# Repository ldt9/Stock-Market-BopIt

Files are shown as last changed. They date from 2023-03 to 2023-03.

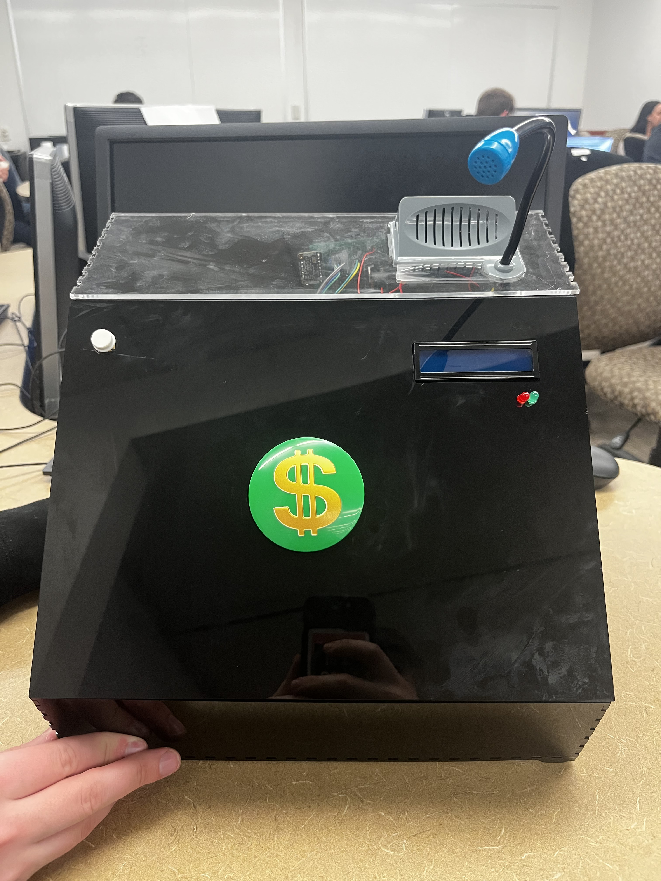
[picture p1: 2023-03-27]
Enclosure Design Files/ProductImages/IMG_0331.jpg

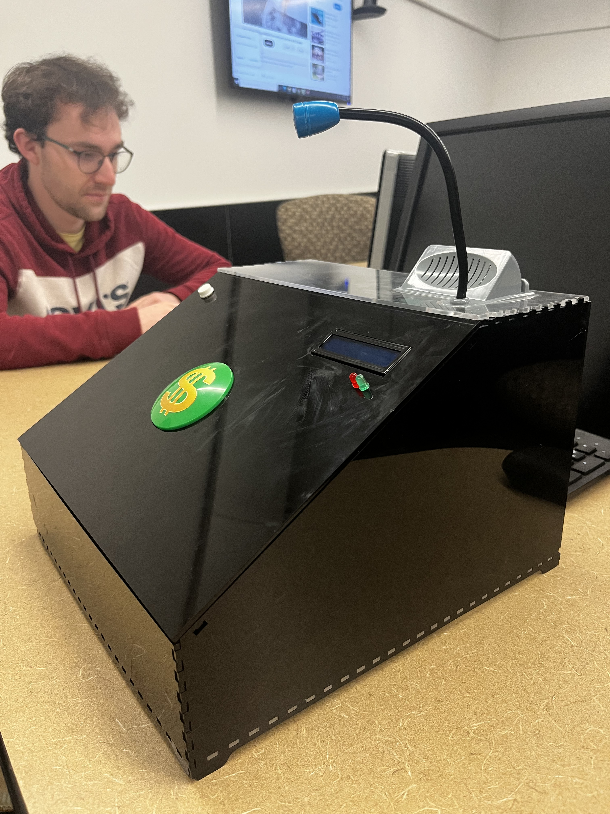
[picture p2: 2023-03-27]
Enclosure Design Files/ProductImages/IMG_0332.jpg

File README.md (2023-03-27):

# Stock Market Bopit

## Project Overview

The Stock Market Bopit is a game that allows players to simulate trading stocks by using physical actions to make decisions. The game has three different actions that players can take: hitting a "Buy" button to buy a stock, yelling into the sound detector to sell a stock, and shaking the device to hold onto a stock.

The game was created by my group for a Junior Design project as part of my ECE Courses at the University of Pittsburgh. It is modeled to look like a toy cash register, but with more functionality.

## Technologies Used

- Arduino Uno
- Sound Detector
- Buttons
- Gyroscope
- LEDs

## How to Play

1. Flip the switch on the rear of the unit to turn the machine on.
2. Press the start button to begin the game.
2. The game will display a required action such as Buy, Sell or Hold.
3. To buy the stock, hit the "Buy" button.
4. To sell the stock, scream "Sell" into the microphone.
5. To hold onto the stock, shake the Bopit. 
6. Each time a player successfully completes an action, they will recieve one point, and the game time per action will decrease to make it faster and more difficult.
6. The game will continue until the player reaches a score of 99 or fails to complete an action in the required amount of time.
7. The player's final score will be based on the total number of successful bopits.

## Files in the Repo

There are a few files in this repository that are noteable. First is the code. It has the file extension `.ino` which is meant to be loaded into an Arduino. The code contains the game loop, sounds, and over functionality of the Bop It. Next is the enclosure design. This has the file extension `.svg` which is meant to be loaded into a laser cutter or another milling machine. We used laser cut arylic for our design as you can see in the photos below. Lastly are the Altium files. These contain gerber files that are meant to be sent to PCB manufacturer for milling. You could use these, along with the included schematics in order to recreate our Bop It.

## Photos








## Conclusion

The Stock Market Bopit was a fun and interactive way to learn about Arduino's and how to interface with them. My group and I had a fun time making this project, and it taught us many valuable lessons about circuit design, programming, and most of all, teamwork!

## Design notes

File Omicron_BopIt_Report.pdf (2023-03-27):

# Design Project 2: Bop-it! Project Final Report

### Design Overview

The Stock Market Bop-It game is an interactive simulation of stock trading where players use physical actions to make decisions. The game involves three main actions: hitting the "Buy" button to purchase a stock, yelling into the sound detector to sell a stock, and shaking the device to hold onto a stock. The Bop-It design is modeled after a cash register, adding to its realism.
Originally, we had thought to use a microphone for the sound input. However, upon further review and research, we determined that a microphone was unnecessary as it would require an amplifier and recording capabilities, which were not needed for detecting sound. Instead, we replaced the microphone with a sound detector, simplifying the design.
Initially, the design for the Bop-It game included an RFID card swipe to start the game. During testing, it was discovered that the RFID scanner required a 3.3V input, while the rest of the circuit used a 5V input. We evaluated alternative RFID scanners, but after reviewing the (few good) available libraries, we decided to replace the RFID card swipe with a button, as it was not critical to the game's functionality and only an added feature.

### Design Verification

The design verification for the Bop-It first included tests of our sensors. These tests revolved around gaining a better understanding of how they worked and how to best interface them with the Arduino. This first set of testing lead us to our first change in our device which was removing the RFID card swipe and replacing it with a button for the start. We made this decision after extensive testing on the RFID card swipe and realized that it was going to be much less reliable and cause more problems than it was worth, leading to replacing it with a simple button.
The next step in our design verification was to interface all the sensors with the Arduino. This process was crucial for further progress as it set up the layout for the PCB and allowed us to finalize the software for a full test of our initial prototype. This step involved us using a breadboard and the datasheets for the sensors to determine where we must interface the sensors.
The last thing we did during design verification was to determine the best way to make the enclosure. At first, we started with the idea of gutting an existing toy cash register and putting our Bop-It inside. This plan got changed as we realized the many problems that come up when using a pre-existing enclosure including hole sizing. Our plan after that included changing our enclosure design to one that we would laser cut holes to better fit all our sensors and our general design.

### Electronic Design Implementation

To implement the PCB design, we began by designing a schematic based on testing of each component used in the circuit. To ensure error-free implementation, the circuit was first fully tested on a breadboard before the PCB schematic was created. To organize the multiple pin outputs on the circuit, we created an excel file for each pin output on the ATMEGA328P IC.
For a stable power supply, we added a voltage regulator to the circuit to provide a constant and controlled voltage to the rest of the circuit. Additionally, a capacitor was included from power to ground and a crystal with two capacitors on opposite sides of the crystal to set up the ATMEGA chip and ensure its proper functioning. To connect components like the gyroscope, sound sensor, LCD screen, start and buy buttons, and speaker, we used jumper components, since these components are not attached to the board but rather to the housing design.
A potentiometer was added in series with the speaker to control the volume level before it was put into the housing. Two LED lights and resistors were also added to the design to signify if the action was completed within the time frame for our game. We included a jumper to reprogram the ATMEGA in case we found a flaw in the code and needed to easily change it.
To lay out the PCB, we placed the jumpers for the gyroscope, sound sensor, LCD screen, buy and start buttons, speaker, pins for reprogramming, and power supply around the perimeter of the board for an organized way of connecting the board to the components. The ATMEGA328P IC was placed in the middle of the board since most components were connected to it, making routing more efficient. The potentiometer was also placed in the middle for easier adjustment of resistance without interfering with wires coming off the board.
The two capacitors were placed to the left of the ATMEGA328P IC, as that was the most efficient route without interfering with the rest of the circuit. The 5V regulator was placed next to the capacitor across the power and ground terminals, which is next to the power jumper. The remaining diodes and resistors were placed below the crystal to fill the board. We used an autoroute program to correctly route the circuit and had no errors in routing but faced some trouble in routing the circuit to the buy button input due to its unique design. To solve this problem, we soldered two jumper wires from the button leads of the cash button PCB through the speaker holes and to the main PCB.
During testing, we found that the buy button would only work as an input if it was turned on, and that whenever the main power supply was turned off, the cash button would make a sound even when it was not pressed. We also discovered that we initially used too high of a resistance for the green and red LEDs, resulting in them being too dim, so we replaced the 10k resistor with a 1k resistor to achieve the desired brightness level.
One error we made was not including a power switch on the board, but we easily rectified this by connecting the positive lead from the battery wire to a switch, which had a jumper wire to the positive end of the power supply jumper, while the negative end of the battery connected to the ground terminal jumper.

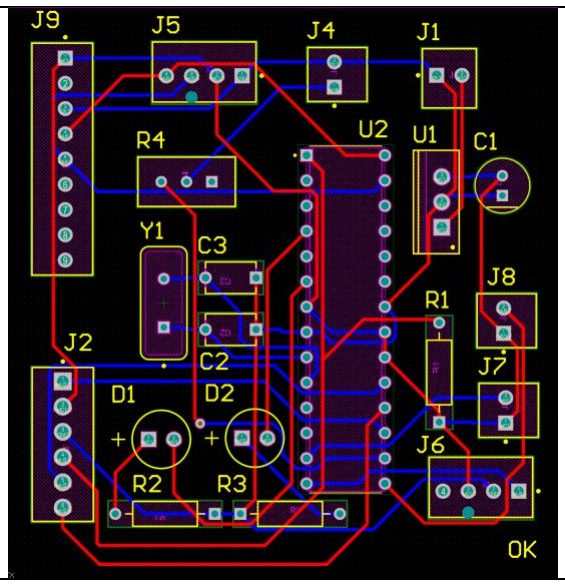
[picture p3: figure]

PCB Layout of circuit.

### Software Implementation

The software developed for this project is based on Arduino. The main functionalities of the software are to read data from sensors, display prompts on the LCD screen, play sound, and handle user input. The sensors used in the project are a gyroscope, sound detector, and buttons. The LCD screen is used to display instructions to the user. The code is structured in a way that a game loop is run continuously until the user fails to complete a task in time or reaches a score of 99. During each iteration of the game loop, the state of each sensor is read and instructions are displayed on the LCD screen.
The subroutines developed and used in the final software implementation are as follows:
1. setup(): This subroutine is used to initialize the variables and sensors used in the project.
2. loop(): This subroutine is the main game loop, which runs continuously until the user fails to complete an action in time or reaches a score of 99. The loop first reads the state of the sensors and decides which random action to prompt the user to perform. This decision is fed to the actionDetector() sub routine where it displays the unique instruction on the LCD screen, makes a distinct noise and waits for user input. If the user performs the action within the given time, the score is incremented, and the loop continues. If the user fails to perform the action within the given time, the loop is terminated, and the final score is displayed on the LCD screen.
3. actionDetector(int action, int actionPin, String actionText, bool digital): This subroutine is called when the user is prompted to perform one of the three actions. It plays the melody associated with the action, displays the required action to the LCD screen and lights up the green LED upon completion, or the red LED upon failure. It can handle both digital and analog sensors.
4. playMelody(int melody[], int length): This subroutine is used to play the melody associated with each action. It takes an array of notes and their duration as input and plays them using the tone() function.
The code is structured in a modular way, with each subroutine responsible for a specific task. This makes the code easy to understand, modify, and maintain. The use of descriptive function names also helps in understanding the purpose of each subroutine. The code follows good software engineering practices, such as modularization, documentation, and readability. The code is also well commented, making it easy to understand for other developers.
The design process involved breaking down the problem into smaller tasks and implementing them one by one. The first step was to initialize the sensors and test their functionality. Then we designed the game loop and implemented the code to read sensor data and display instructions on the LCD screen. We then added sound and LED feedback to the game. The main challenge in the design process was to handle user input within a limited time frame. We overcame this challenge by using the millis() function to measure the time elapsed and terminate the loop if the user fails to perform the action within the given time. We also had to optimize the code to make it run efficiently within the limited resources of the Arduino board.

### Enclosure Design

At first our enclosure design was going to be of a toy cash register with 3D printed parts to make the hole fit our needs. This idea soon changed as we worked through the process of disassembly and eventually changed to using a laser cutter to create our enclosure. We decided on this design method due the simplicity of our box allowing for quick and easy laser cutting.
The structure of our enclosure is meant to mimic the look and size of a cash register to fit the theme of our Bop-It. There are a couple of cutouts on our Bop-It to allow interactions with our inputs. There was a total of 6 cutouts all done with the laser cutter. The cutouts hold the LED screen, LED lights, speaker, sound detector, buttons, and a power switch. Our design also features a piece of a toy cash register that holds both the speaker and sound detector while adding an aesthetic microphone to make the feel and visual appeal of our Bop-It more like a cash register.
For our manufacturing process we used laser cutting. Because of the size of our Bop-It, laser cutting wasn’t as simple as we had thought. One of our pieces was too big to be cut out in one piece. The solution to this problem was to modify the cutout to make it 2 sperate pieces. One unplanned feature we got from laser cutting that we didn’t really plan was for a clear top and bottom, however, this was a happy accident as these pieces allow you to see into the enclosure and look at the circuit without opening the box.

### Assembly and System Integration

For the PCB assembly, pinheads were used at each of the jumpers and soldered accordingly, with the exception for the gyroscope which had pinheads soldered to it. These pinheads fit perfectly into the PCB and then soldered. Once everything was soldered female to female, and female to male wires to connect each circuit component to the PCB and give each component the length needed to fit within the design.
Our design had a couple steps in assembly. The first was to get the pieces without cutouts together to form a base for the rest of the enclosure to be built on. This proved to be more challenging than we thought as the pieces were cut to fit very tightly together leading to problems assembling and lead to some pieces cracking or breaking during assembly. The next step in this process was to attach the inputs and outputs to their intended cutouts with hot glue. This also had some problems due to tight cutout and we had to use a Dremel to remove the extra material. Another problem encountered was that one of our cutouts was oriented the wrong way and lead to the top not fitting on as intended.
We tested our design thoroughly at each step of the way first starting with the PCB implementations. Then as we attached more parts to the enclosure, we tested it incrementally before fully enclosing the design. One modification we made to our design was an added set of pins to our board to allow easy access to the Arduino for code updates and changes if we ever needed it.

### Design Testing

Electronic Design Testing
There wasn’t much debugging to do throughout the whole process other than our big green button in the center of the product. Since this was already made into a separate product, and there was power used to make a “Cha-Ching” noise, when we tried to implement it into our design it didn’t work as an input to the Arduino at first. We hypothesized that there was probably a different part of the device it was grounding to and not giving the Arduino a high signal, it was looking for. It took a few times of resoldering it, but after trying a few permutations about the button leads, we landed on a set that worked both as an input and to produce the sound we were looking for.
One small thing that had to be debugged was the LEDs. At first, they did not light up but upon further testing it turned out they were put in the wrong way. On the silkscreen there is a “+” sign on the left side of the LED. This turned out to be the negative end of the LED. We have learned now to check to see if the part design in Altium is correct before hooking up a circuit. Since the voltage here was so low it did not damage anything but if it were a higher voltage circuit it could have caused problems and broken components. Also, the LEDs were much dimmer than our group initially intended. To fix this problem our group decided to lower the resistance of the resistors in series with the LEDs from 10k to 5k.

Software Testing
To ensure the software components of our design were functioning correctly, we began by unit testing each individual component. Through this process, we were pleased to discover that our Arduino, programmer, sound detector, buttons, LEDs, gyroscope, LCD screen, and speaker were all functioning flawlessly. The only roadblock we encountered was with our RFID scanner, which required a 3.3V voltage rather than the 5V voltage we were using for the rest of the circuit. While we could have employed a voltage regulator to address this issue, we made the decision to keep the design simple and not introduce multiple voltages. For a comprehensive look at our unit tests and code, you can find them readily available on our GitHub (https://github.com/ldt9/Stock-Market-BopIt) page along with the attached folder.
Once we had confirmed that each individual component was in working order, we then began the process of integrating these individual tests into a cohesive game loop. We began by adding some initial text to the LCD screen and verifying that we could initialize it into both the setup() and loop() routines. We then moved on to integrating the start button and ensuring that an input to the digital pin would correctly prompt different text. With these initial tests in place, we created an action handler that would generate a random action to be displayed on the LCD screen and then wait for user feedback. Initially, we used three buttons to represent the various inputs and to establish functioning digital pins. As we progressed, we slowly swapped out two of these buttons for their respective game input counterparts, testing each new addition as we went along to identify and address any potential issues. Fortunately, each new addition worked exactly as we had intended.
Once we had verified that all inputs were functioning correctly on the breadboard, we then began to add sound to the game. To achieve this, we developed a subroutine to handle generating appropriate noises for each action. After establishing the subroutine, we then integrated it with the action handler and thoroughly tested the game loop. The final step was to add LEDs to indicate when players had made correct or incorrect actions, giving us a fully functional game loop with integrated inputs and outputs. With these tests complete, we were confident in our design and ready to begin the process of soldering the components to the board and assembling it inside the enclosure.

Enclosure Testing
The testing of the enclosure started with our first model for our enclosure and lead to failure after we realized that it would be difficult to get the premade enclosure to fit our needs and it would be simpler to create a laser cut enclosure. After this first design, we moved to a laser cut model of the enclosure which had its own set of problems during testing. The first problems arose as we were assembling it, it included parts cracking or breaking and cutouts being slightly off in size. The last problem we found with the box is the cutout for the top was oriented the wrong way leading to us having to improvise the attachment of the top piece.
Although our design was able to work in the end there were some problems, we would have addressed it if we had more time to cut out a second enclosure. Another part of the testing was making sure our enclosure would hold together as it was played as it had to be shaken for one of the commands. We tested this and the other inputs on the box though a series of test run to ensure the enclosure could handle being played. The only flaw that was found during this testing was that if the buy button is pressed down too hard, it sometimes would shift and not fit into the cutout as well. This didn’t lead to any problems with the inputs, just an aesthetic problem. Below you will find some photos of the fully assembled product.

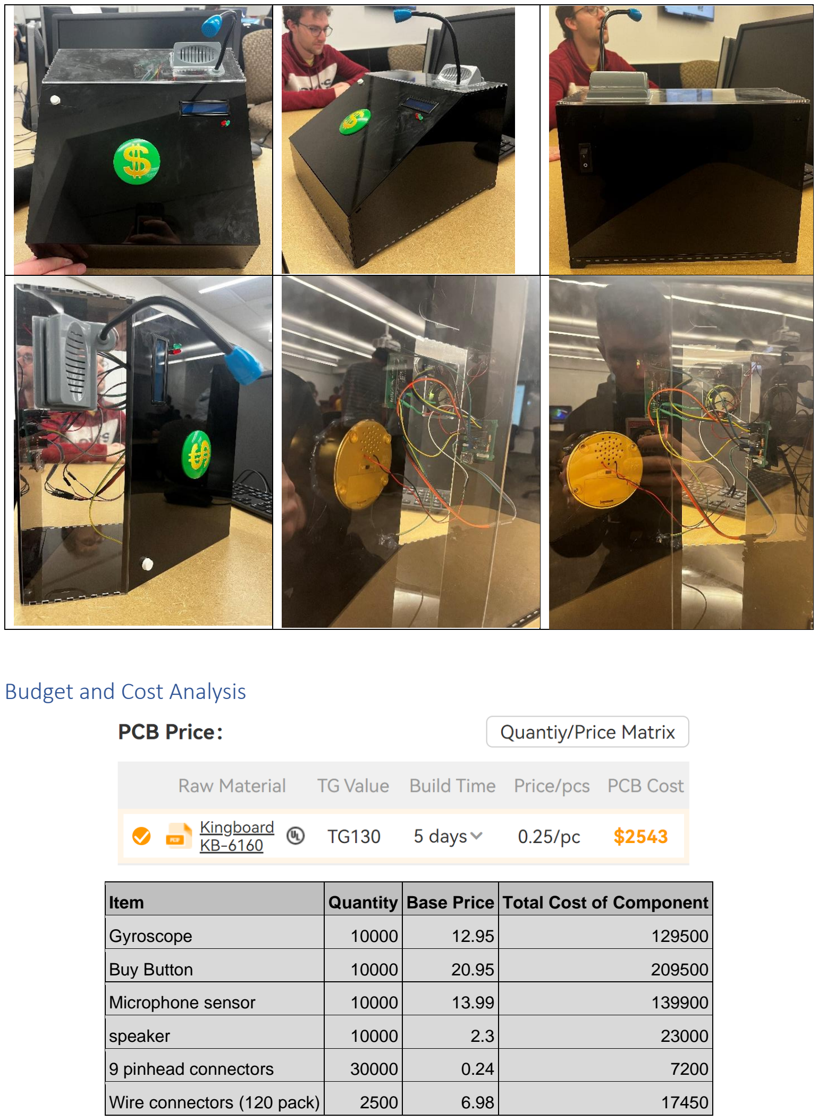
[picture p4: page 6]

### Budget and Cost Analysis

Item | Quantity | Base Price | Total Cost of Component
Gyroscope | 10000 | 12.95 | 129500
Buy Button | 10000 | 20.95 | 209500
Microphone sensor | 10000 | 13.99 | 139900
speaker | 10000 | 2.3 | 23000
9 pinhead connectors | 30000 | 0.24 | 7200
Wire connectors (120 pack) | 2500 | 6.98 | 17450

PCB | 1 | 2543 | 2543
ATMEGA328P IC (10 pack) | 1000 | 50 | 50000
Potentiometer | 10000 | 0.6 | 6000
PVC | 30000 | 35 | 1050000
Crystal | 10000 | 0.18 | 1800
10uf Cap | 10000 | 0.25 | 2500
LED | 20000 | 0.18 | 3600
Resistor | 30000 | 0.45 | 13500

Total cost
of Design

$1,656,493

### Team

Lucas worked on the software aspects of the design. He headed writing the code and uploading it to the Arduino, as well as early stage breadboarding and testing. Then, as we met regularly as a group, we all helped during debugging of the circuit and ultimately creating what would be the final design for the PCB schematic. He also handled creating our initial workflow and GitHub page.
Andrew worked on the enclosure design and helped on the electrical side including back checking the PCB schematic, testing sensors, and organization of inputs. He also handled the enclosure final cutout and assembly as well as assisting in the hookup of the PCB and sensors to the enclosure frame.
Owen designed the PCB and helped to test components. He also worked on the electrical aspect of the buy button. Owen helped with the final assembly of the design, ensuring each component went in the correct spot.
Throughout the design process, we would meet weekly in the Fishbowl for two to three hours at a time to finish our design. We used SMS messaging and email to update each other on the design process as well as meeting times. We felt it was best to meet in person to do the physical testing and assembly, but for report generating and presentations making, it was fine to do it remotely. We believe our team worked great together, and that it was our primary reason for being able to complete our project in such a timely manner.

### Timeline

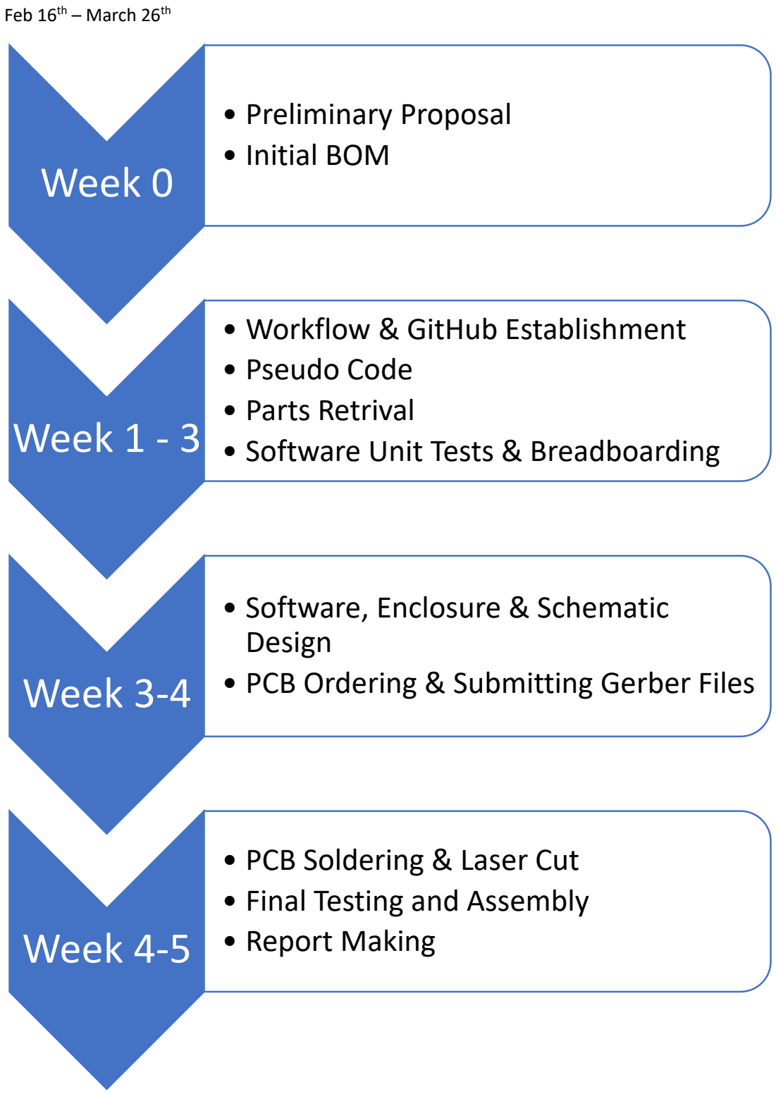
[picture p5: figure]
Feb 16th – March 26th; Week 0; • Preliminary Proposal • Initial BOM; Week 1 - 3; • Workflow & GitHub Establishment • Pseudo Code • Parts Retrival • Software Unit Tests & Breadboarding; Week 3-4; • Software, Enclosure & Schematic Design; Week 4-5; • PCB Soldering & Laser Cut • Final Testing and Assembly • Report Making

## - PCB Ordering & Submitting Gerber Files

### Summary, Conclusions and Future Work

In conclusion, the Stock Market Bop-It game was a great way to learn team building skills and practice real on-the-job skills. Through a series of design iterations and testing, our team was able to refine the initial concept and create a fully functioning prototype. The decision to replace the RFID card swipe with a button, switch to a sound detector for sound input, among many other pivots, were crucial design changes that simplified the circuit and improved its reliability. The team's attention to detail in sensor interfacing and enclosure design resulted in a polished final product that met the project's goals. There are several areas in which the software logic could be improved. For instance, when the ON switch is toggled, the game starts without requiring the start button to be pressed. During initial breadboarding and PCB testing, this didn't pose a problem, but once we assembled everything, the start button was skipped on the first game. After completing or losing the first game, the start button worked correctly, waiting for user input before prompting for actions. We're uncertain why the start button fails during the first round since the code worked correctly initially. Additionally, we overlooked implementing cases where pressing the wrong action would result in losing the game. If we had more time, we would have passed all the sensors to the action handler and added a clause to lose the game if the state of non-prompted actions changed. We could have also attempted to order another RFID scanner running on 5V, but the available libraries were not user-friendly enough for our liking. Lastly, in a later model, we would add a "press to talk" button before speaking into the sound detector to prevent exploiting the loophole of repeatedly pressing the buy button to win the game by triggering the "Cha-Ching" sound.
Reflecting on our Bop-It project, we've identified a few areas in which we could improve the enclosure design. Firstly, we would have opted for a smaller size, as the benefits of a larger size were outweighed by issues with production, assembly, and gameplay. To make the enclosure more visually appealing, we would have liked to add stickers or other decorative elements to showcase the theme and attract more attention to the device. Additionally, we would have improved the box's fit, as the tightness of the enclosure caused some damage during use, and we would have addressed issues with hole sizing to ensure a better fit for components such as the LED screen.
Another significant change we would have made is creating a mount for the battery, as currently, it is only attached to the side of the Bop-It enclosure with hot glue. This would have made replacing the battery difficult, so we would have added a battery mount to the PCB or somewhere in the housing to allow for easy battery replacement if needed. Overall, these improvements would have helped enhance the Bop-It's functionality, ease of use, and aesthetic appeal.

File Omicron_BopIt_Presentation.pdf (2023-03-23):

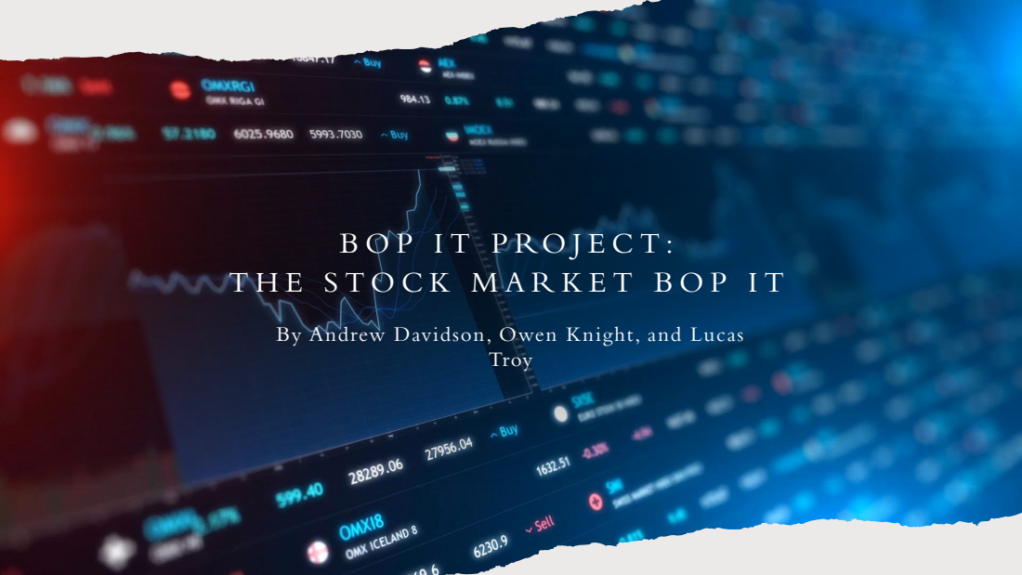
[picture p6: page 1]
Troy

By Andrew Davidson, Owen Knight, and Lucas

# S O F T W A R E I M P L E M E N TAT I O N

- In Arduino’s programming language we instantiate an LSM6DSOX gyroscope, an LCD screen, a sound detector, some buttons, and several pins on the ATMEGA328P to create a game like the Bop It toy with a stock market theme.
- The game has several sensors (buyItPin, sellItPin, and holdItPin) that the user must interact with based on prompts given by the game, such as pressing a button when prompted to “buy,” yelling into the sound detector when prompted to “sell,” and shaking the enclosure when prompted to “hold.”
- There are green and red pins are used to light up the corresponding LEDs, when the user makes a correct or incorrect decision respectively, and the buzzer pin is used to create sound effects through an 8 Ohm speaker.
- The code initializes various variables and arrays, such as the time the user must complete each action within, the current score, and a set of musical notes that can be played through the buzzer.
- The program includes a game loop that waits for user input based on the prompt given by the game. If the user completes the action before the time limit expires, the score is incremented, and the next action is prompted. If the user fails to complete the action or time runs out, the game is over, and the final score is displayed on the LCD screen.
- We have tested the power (input), buttons (input), sensors (input), ATMEGA328P (control) and speaker (output) on a breadboard thoroughly to know the circuit design should work once established on the PCB.
- For simplicity, no code is show, but a repo of this code can be viewed here. (https://github.com/ldt9/Stock-Market-BopIt)

# E N C L O S U R E D E S I G N

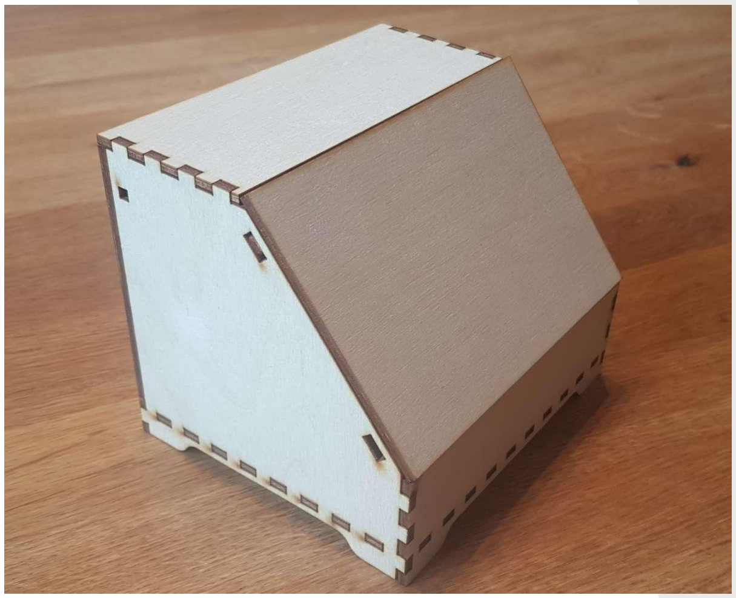
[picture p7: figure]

### - The design is based off the shape of a cash register to fit the theme of our bot-it

game.

- The inputs and outputs such as buttons,

### switches, LED displays, and microphones will have cutouts to allow the user to

interact with them.

### - This design process was picked due to the simplicity of our encloser allowing for it

to be easily done on the laser cutter.

### - The board will be mounted on the floor of the enclosure and the sensors and

outputs will be mounted on their cutouts.

# P C B D E S I G N

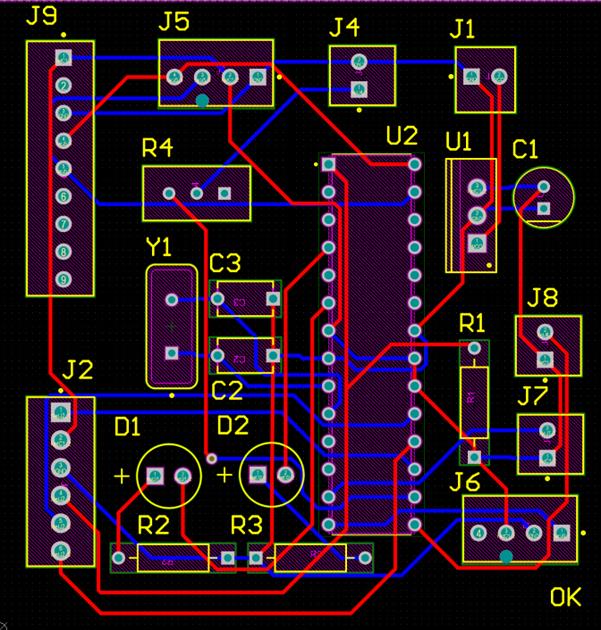
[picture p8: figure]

### •For organization in the enclosure jumper pins are on the outside of the board. Wires connected to these jumpers will be used to put the circuit components in the spot designed in the enclosure •J2 is for uploading new code to the ATMEGA328P IC if need be

•Gyroscope (J9) will be mounted to board.

### •Circuit will be powered by 9V battery (J1) and a 5V regulator (U1) is used to keep the power constant and controlled

## F I N A L D E S I G N O F T H E S T O C K M A R K E T

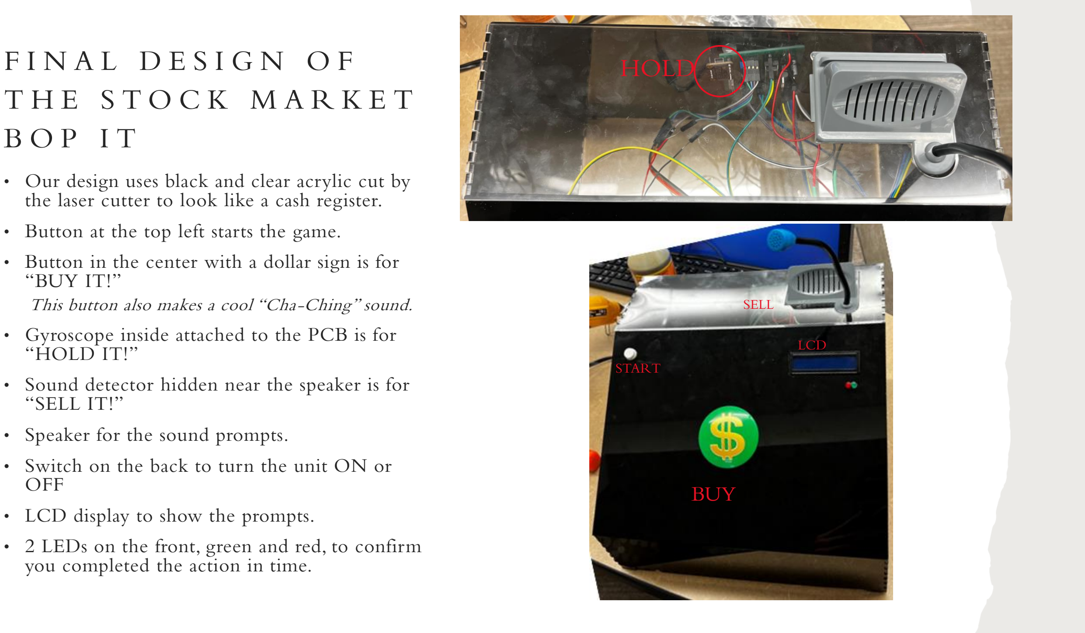
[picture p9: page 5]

## B O P I T

- Our design uses black and clear acrylic cut by the laser cutter to look like a cash register.
- Button at the top left starts the game.
- Button in the center with a dollar sign is for “BUY IT!”
This button also makes a cool “Cha-Ching” sound.
- Gyroscope inside attached to the PCB is for “HOLD IT!”
- Sound detector hidden near the speaker is for “SELL IT!”
- Speaker for the sound prompts.
- Switch on the back to turn the unit ON or OFF
- LCD display to show the prompts.
- 2 LEDs on the front, green and red, to confirm you completed the action in time.

## HOLD

START

BUY

LCD

SELL

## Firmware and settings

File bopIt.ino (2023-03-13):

//TODO:
// Add Speaker functionality

// https://mhsp18object.wordpress.com/2018/05/06/project-2-diy-arduino-sensor-bop-it/
#include <string.h>

//Create an Instance of the Gryroscope
#include <Arduino_LSM6DSOX.h>

//Initialize the LCD Screen
#include <LCD_I2C.h> // LCD Library
LCD_I2C lcd(0x27, 16, 2); // Default address of most PCF8574 modules, change according

//sensor pins
int buyItPin = 7;
int sellItPin = 8;
int holdItPin = 6; //Use gyroscope pitch and yaw
int bypass = 9; //To bypass the RFID Scanner during testing
int greenPin =  2;
int redPin = 4;
int buzzer = 10;

//action to perform during each step
long action = 0;

//reference variables for sensor states
int state1 = 0;
int state2 = 0;

//time user has to complete action in milliseconds and related variables for time keeping
unsigned long gameRate = 10000;
unsigned long timeOfPrompt;
unsigned long timeElapsed;

//variable to control game loop
int keepPlaying = 0;
int actionCompleted = 0;
int score = 0;
int finalScore = 0;
int bypassTrue = 0;

//define tones
#define NOTE_B0 31
#define NOTE_C1 33
#define NOTE_CS1 35
#define NOTE_D1 37
#define NOTE_DS1 39
#define NOTE_E1 41
#define NOTE_F1 44
#define NOTE_FS1 46
#define NOTE_G1 49
#define NOTE_GS1 52
#define NOTE_A1 55
#define NOTE_AS1 58
#define NOTE_B1 62
#define NOTE_C2 65
#define NOTE_CS2 69
#define NOTE_D2 73
#define NOTE_DS2 78
#define NOTE_E2 82
#define NOTE_F2 87
#define NOTE_FS2 93
#define NOTE_G2 98
#define NOTE_GS2 104
#define NOTE_A2 110
#define NOTE_AS2 117
#define NOTE_B2 123
#define NOTE_C3 131
#define NOTE_CS3 139
#define NOTE_D3 147
#define NOTE_DS3 156
#define NOTE_E3 165
#define NOTE_F3 175
#define NOTE_FS3 185
#define NOTE_G3 196
#define NOTE_GS3 208
#define NOTE_A3 220
#define NOTE_AS3 233
#define NOTE_B3 247
#define NOTE_C4 262
#define NOTE_CS4 277
#define NOTE_D4 294
#define NOTE_DS4 311
#define NOTE_E4 330
#define NOTE_F4 349
#define NOTE_FS4 370
#define NOTE_G4 392
#define NOTE_GS4 415
#define NOTE_A4 440
#define NOTE_AS4 466
#define NOTE_B4 494
#define NOTE_C5 523
#define NOTE_CS5 554
#define NOTE_D5 587
#define NOTE_DS5 622
#define NOTE_E5 659
#define NOTE_F5 698
#define NOTE_FS5 740
#define NOTE_G5 784
#define NOTE_GS5 831
#define NOTE_A5 880
#define NOTE_AS5 932
#define NOTE_B5 988
#define NOTE_C6 1047
#define NOTE_CS6 1109
#define NOTE_D6 1175
#define NOTE_DS6 1245
#define NOTE_E6 1319
#define NOTE_F6 1397
#define NOTE_FS6 1480
#define NOTE_G6 1568
#define NOTE_GS6 1661
#define NOTE_A6 1760
#define NOTE_AS6 1865
#define NOTE_B6 1976
#define NOTE_C7 2093
#define NOTE_CS7 2217
#define NOTE_D7 2349
#define NOTE_DS7 2489
#define NOTE_E7 2637
#define NOTE_F7 2794
#define NOTE_FS7 2960
#define NOTE_G7 3136
#define NOTE_GS7 3322
#define NOTE_A7 3520
#define NOTE_AS7 3729
#define NOTE_B7 3951
#define NOTE_C8 4186
#define NOTE_CS8 4435
#define NOTE_D8 4699
#define NOTE_DS8 4978
#define REST 0


// change this to make the song slower or faster
int tempo = 360;

int buyMelody[] = {
  //Cantina Band
  NOTE_B4,-4, NOTE_E5,-4, NOTE_B4,-4, NOTE_E5,-4,
};

int sellMelody[] = {

  // Super Mario Brothers 
  NOTE_G5,8, NOTE_FS5,8, NOTE_F5,8, NOTE_DS5,4,
};

int holdMelody[] = {

  //Keyboard Cat
  NOTE_C4,4, NOTE_E4,4, NOTE_G4,4, NOTE_E4,4,  
};

// sizeof gives the number of bytes, each int value is composed of two bytes (16 bits)
// there are two values per note (pitch and duration), so for each note there are four bytes
int buyNotes = sizeof(buyMelody) / sizeof(buyMelody[0]) / 2;
int sellNotes = sizeof(sellMelody) / sizeof(sellMelody[0]) / 2;
int holdNotes = sizeof(holdMelody) / sizeof(holdMelody[0]) / 2;

// this calculates the duration of a whole note in ms
int wholenote = (60000 * 4) / tempo;

int divider = 0, noteDuration = 0;

void setup() {
	//initialize software serial monitor and give a delay for lcd to load
	lcd.begin();
  lcd.backlight();
	delay(500);

  //Initialize the gyroscope
  IMU.begin();

	//setting pin modes
	// pinMode(rfidScannerPin, INPUT);
	pinMode(buyItPin, INPUT);       //Button controls this pin
	pinMode(sellItPin, INPUT);      //Sound detector controls this pin
  pinMode(bypass, INPUT);         //Button to start game
  pinMode(greenPin, OUTPUT);
  pinMode(redPin, OUTPUT);
  pinMode(buzzer, OUTPUT);

	char scoreString[10];
}

void actionDetector(int action, int actionPin, String actionText, bool digital) {
	//if action selected is one, then tell user to "Buy It"
	// lcd.clear();
  // lcd.print(actionText);

  float x, y, z;
  //reset LED States
  digitalWrite(greenPin, LOW); // Green LED
  digitalWrite(redPin, LOW); // Green LED


	//Read button value to track if user has changed it once prompted
	if (digital) {
		state1 = digitalRead(actionPin);
	}
	else {
		// state1 = analogRead(sensor); //Adjust this for the gyroscope
    IMU.readAcceleration(x, y, z);
    // lcd.clear();
    state1 = int(x) + int(y) + int(z);
    // lcd.print(roll);
    // lcd.clear();
  }

	//write "Buy It" to lcd to prompt user
  lcd.clear();
	lcd.print(actionText);

	//record the time you prompted the user
	timeOfPrompt = millis();
	timeElapsed = millis() - timeOfPrompt;

	//while loop checking if user completed action in allowed time
	while (timeElapsed < gameRate && actionCompleted == 0){
		//read switch for comparing to check if action was completed
		if (digital) {
			state2 = digitalRead(actionPin);
		}
		else {
			// state2 = analogRead(sensor);
      IMU.readAcceleration(x, y, z);
      // lcd.clear();
      state2 = int(x) + int(y) + int(z);
      // lcd.print(yaw);
      // lcd.clear();
		}
		//if the switch state changed, then the user completed action
		if (state2 != state1){
			actionCompleted = 1;
			score = score +1;
			gameRate = gameRate - (gameRate * .05);
      delay(500);
		}

		//recalculate timeElapsed
		timeElapsed = millis() - timeOfPrompt;
	}

	//once while loop stops (either due to time running out or completing action)
	//check to see if action was comleted and adjust settings accordingly
	if (actionCompleted == 1 && score == 99){
    lcd.clear();
    lcd.print("Game Won!");
    delay(750);
    finalScore = score;
    gameRate = 10000;
    score = 0; //reset score to 0 for new game
		char scoreString[10];
		sprintf(scoreString,"%4d",finalScore);
		keepPlaying = 0;
    lcd.clear();
		lcd.print("GAME OVER!");
    lcd.clear();
		lcd.write("Score");
    lcd.clear();
		lcd.print(scoreString);

		delay(2000);
  }
  else if (actionCompleted == 1){
    lcd.clear();
		lcd.print("action completed");
    digitalWrite(greenPin, HIGH); // Green LED
		// tone(speakerPin, 10000, 250); // Adust to a better win sound
		delay(250);
		// noTone(speakerPin);
	}
	else if (actionCompleted == 0){
    lcd.clear();
		lcd.print("action failed");
    digitalWrite(redPin, HIGH); // Red LED
		delay(750);
    // tone(speakerPin, 10000, 250); // Adust to a better Lose sound
    delay(250);
    // noTone(speakerPin);
		finalScore = score;
    gameRate = 10000;
    score = 0; //reset score to 0 for new game
		char scoreString[10];
		sprintf(scoreString,"%4d",finalScore);
		keepPlaying = 0;

    lcd.clear();
		lcd.print("GAME OVER!");
    lcd.clear();
		lcd.print("Final Score: ");
    // lcd.clear();
    lcd.setCursor(0, 1);
    lcd.print(scoreString);

		delay(2000);
    digitalWrite(redPin, LOW);                        
	}
}

void loop() {
	// display game start code on lcd
  lcd.clear();
  lcd.print("   Press  the"); 
  lcd.setCursor(2, 1);
  lcd.print("Start Button!");
  delay(500);

	//If button is pressed, go into game.
  bypassTrue = digitalRead(bypass);
	if (bypassTrue){

	//variable to control the while loop running the game until user has failed
	keepPlaying = 1;

		//while loop to keep running game until user has failed and "keepPlaying" is set to zero
		while (keepPlaying != 0) {
			//pick an action to assign the user via a random number generator – upper bound is exclusive
			action = random(1,4);
			actionCompleted = 0;
      lcd.clear();
			lcd.print(action);
      lcd.clear();

			//if else statements to prompt user and check action
		    switch(action) {
				case 1:
            // iterate over the notes of the melody.
            // Remember, the array is twice the number of notes (notes + durations)
            for (int thisNote = 0; thisNote < buyNotes * 2; thisNote = thisNote + 2) {

              // calculates the duration of each note
              divider = buyMelody[thisNote + 1];
              if (divider > 0) {
                // regular note, just proceed
                noteDuration = (wholenote) / divider;
              } else if (divider < 0) {
                // dotted notes are represented with negative durations!!
                noteDuration = (wholenote) / abs(divider);
                noteDuration *= 1.5; // increases the duration in half for dotted notes
              }

              // we only play the note for 90% of the duration, leaving 10% as a pause
              tone(buzzer, buyMelody[thisNote], noteDuration * 0.9);

              // Wait for the specief duration before playing the next note.
              delay(noteDuration);

              // stop the waveform generation before the next note.
              noTone(buzzer);
            }
					actionDetector(action, buyItPin, "Buy It!", 1);
					break;
				case 2:
            // iterate over the notes of the melody.
            // Remember, the array is twice the number of notes (notes + durations)
            for (int thisNote = 0; thisNote < sellNotes * 2; thisNote = thisNote + 2) {

              // calculates the duration of each note
              divider = sellMelody[thisNote + 1];
              if (divider > 0) {
                // regular note, just proceed
                noteDuration = (wholenote) / divider;
              } else if (divider < 0) {
                // dotted notes are represented with negative durations!!
                noteDuration = (wholenote) / abs(divider);
                noteDuration *= 1.5; // increases the duration in half for dotted notes
              }

              // we only play the note for 90% of the duration, leaving 10% as a pause
              tone(buzzer, sellMelody[thisNote], noteDuration * 0.9);

              // Wait for the specief duration before playing the next note.
              delay(noteDuration);

              // stop the waveform generation before the next note.
              noTone(buzzer);
            }
					actionDetector(action, sellItPin, "Sell It!", 1);
					break;
				case 3:
            // iterate over the notes of the melody.
            // Remember, the array is twice the number of notes (notes + durations)
            for (int thisNote = 0; thisNote < holdNotes * 2; thisNote = thisNote + 2) {

              // calculates the duration of each note
              divider = holdMelody[thisNote + 1];
              if (divider > 0) {
                // regular note, just proceed
                noteDuration = (wholenote) / divider;
              } else if (divider < 0) {
                // dotted notes are represented with negative durations!!
                noteDuration = (wholenote) / abs(divider);
                noteDuration *= 1.5; // increases the duration in half for dotted notes
              }

              // we only play the note for 90% of the duration, leaving 10% as a pause
              tone(buzzer, holdMelody[thisNote], noteDuration * 0.9);

              // Wait for the specief duration before playing the next note.
              delay(noteDuration);

              // stop the waveform generation before the next note.
              noTone(buzzer);
            }
					actionDetector(action, holdItPin, "Hold It!", 0);
					break;
        }
		}
	}
}

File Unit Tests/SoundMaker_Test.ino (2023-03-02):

/*
 * Copyright 2018 Code and Make (codeandmake.com)
 * 
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
 * THE SOFTWARE IS PROVIDED "AS IS", WITHOUT WARRANTY OF ANY KIND, EXPRESS OR
 * IMPLIED, INCLUDING BUT NOT LIMITED TO THE WARRANTIES OF MERCHANTABILITY,
 * FITNESS FOR A PARTICULAR PURPOSE AND NONINFRINGEMENT. IN NO EVENT SHALL THE
 * AUTHORS OR COPYRIGHT HOLDERS BE LIABLE FOR ANY CLAIM, DAMAGES OR OTHER
 * LIABILITY, WHETHER IN AN ACTION OF CONTRACT, TORT OR OTHERWISE, ARISING FROM,
 * OUT OF OR IN CONNECTION WITH THE SOFTWARE OR THE USE OR OTHER DEALINGS IN THE
 * SOFTWARE.
 */

/*
 * A simple project that demonstrates how to make music using an Arduino.
 * 
 * This code accompanies the following tutorial: https://youtu.be/Z1YvIFUIhLs
 */

// Pin to which an 8 Ohm speaker is connected (use a 150 - 220 Ohm resistor)
#define speakerPin 10

// Tempo (beats per minute)
#define bpm 96

// Gap between notes. This is expressed as percentage of time between 2 beats.
#define noteGapPercentage 10

/*
 * 2D array containing the notes to be played
 * A note comprises of two values:
 *  * The first value determines the frequency of the note.
 *    This is expressed as the number of a key on an 88-key piano (1 - 88)
 *    A number outside this range can be used (e.g. 0) to create a gap 
 *  * The second value determines the duration:
 *    * 1 represents a whole note (spans 4 beats)
 *    * 2 represents a half note (spans 2 beats)
 *    * 4 represents a quarter note (spans 1 beat)
 *    * 8 represents an eighth note (spans 0.5 beat)
 *      etc.
 */
uint8_t notes[][2] = {
  {35,4}, {35,4}, {42,4}, {42,4}, {44,4}, {44,4}, {42,2},
  {40,4}, {40,4}, {39,4}, {39,4}, {37,4}, {37,4}, {35,2},
  {42,4}, {42,4}, {40,4}, {40,4}, {39,4}, {39,4}, {37,2},
  {42,4}, {42,4}, {40,4}, {40,4}, {39,4}, {39,4}, {37,2},
  {35,4}, {35,4}, {42,4}, {42,4}, {44,4}, {44,4}, {42,2},
  {40,4}, {40,4}, {39,4}, {39,4}, {37,4}, {37,4}, {35,2}
};

// Time between two beats in microseconds (equal to length of a quarter note)
#define beatDuration (60.0 / bpm) * 1000000L

// Time of the gap between two notes in microseconds
#define noteGap beatDuration * (noteGapPercentage / 100.0)

void setup() {
  // Set the speakerPin as an output
  pinMode(speakerPin, OUTPUT);

  // Iterate over the notes array
  for(int i = 0; i < (sizeof(notes) / sizeof(*notes)); i++) {
    // pass the key number and note type
    playNote(notes[i][0], notes[i][1]);
  }
}

/*
 * Plays an individual note.
 * 
 * keyNumber - The key number (1 - 88)
 * noteType - The note type (1, 2, 4, 8, etc.)
 */
void playNote(uint8_t keyNumber, uint8_t noteType) {
  long halfPeriod = getPeriodForKey(keyNumber) / 2;
  long noteDuration = beatDuration * (4.0 / noteType);
  long elapsed = 0;

  // While we have a note to play
  while(halfPeriod > 0 && elapsed < (noteDuration - noteGap)) {
    // Set speakerPin high for half of the period
    digitalWrite(speakerPin, HIGH);
    wait(halfPeriod);

    // Set speakerPin low for half of the period
    digitalWrite(speakerPin, LOW);
    wait(halfPeriod);

    // Update the amount of time that has elapsed
    elapsed += halfPeriod * 2;
  }

  /*
   * Gap between notes. Calculated using 'elapsed' to minimise timing errors
   * and ensure that the correct gap occurs whenever getPeriodForKey() returns
   * zero. 
   */
  wait(noteDuration - elapsed);
}

/*
 * Returns the period for a key or zero for key numbers outside the range of 1 -
 * 88.
 * 
 * keyNumber - The key number (1 - 88)
 */
long getPeriodForKey(uint8_t keyNumber) {
  // If the key is between 1 and 88
  if(keyNumber >= 1 && keyNumber <= 88) {
    // Return the period (one second divided by the frequency of the key)
    return 1000000L / (pow(2.0, (keyNumber - 49.0) / 12.0) * 440.0);
  }

  // Otherwise return zero
  return 0;
}

/*
 * Delay for a number of microseconds. This is necessary because
 * delayMicroseconds() has an upper limit.
 * 
 * us - The delay in microseconds
 */
void wait(long us) {
  // First delay for the number of whole milliseconds using delay()
  delay(us / 1000);
  // Then delay for the remainder of microseconds using delayMicroseconds()
  delayMicroseconds(us % 1000);
}

void loop() {
  // Not used. Music will play once.
}

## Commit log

2023-02-25 Added Accelerometer Unit Test
    This program tests the GY-521 accelerometer and prints the output to an LCD screen.
2023-02-26 Tested a different Accelerometer
    The other test for the Accelerometer is good, but the module doesn't work. This module works way better.
    [SimpleAccelerometer.ino]
2023-02-26 Updated Game Loop and Added Funtionality
    Added working user input for sound detector, gyroscope and RFID scanner
2023-02-26 Updated BopIt code
    Updated the game loop to use RFID Scanner correctly for input to start the game
    Updated the action detector to read analog inputs correctly
    [bopIt.ino]
2023-02-28 Updated Gyroscope for initialization
2023-03-27 Added GERBER Files
    [Bopit.PrjPcb, Bopit_pcb.PcbDoc]
2023-03-27 Added Enclosure Design Files
